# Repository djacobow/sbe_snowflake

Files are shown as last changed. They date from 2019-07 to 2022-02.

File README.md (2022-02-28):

# Electronic Snowflake

South Berkeley Electronics Snowflake

This is the public repo for the
[South Berkeley Electronics Snowflake](https://www.southberkeleyelectronics.com/home/snowflake).

SBE has chosen to discontinue this item and instead make the design
available publically for people who would like to build their
own.

The design is licensed under the
[Create Commons Attribution - ShareAlike 3.0 license](https://creativecommons.org/licenses/by-sa/3.0/), a copy of which is included in this repository.

## What you will find here

In this repo, you should find:

### Hardware

* DipTrace files for the design
* gerbers, exported from Diptrace, if you just went to send them to a PCB house
  for manufacture. The design uses a simple 2-layer board that can be manufactured
  with the basic offerings from PCBWay, JLCPCB and others.
* A complete BOM that you can use to order parts

I cannot provide detailed guidance on how to order and complete a PCB.
There is nothing particularly difficult about this design, but in order to
complete it you should be able to solder a QFP chips, as well as 0805 size
passives. Also, the WS2812C LEDs that the design is built around are quite
sensitive to heat, and not particularly easy to solder without damage.

### Software

* There are two versions of the firmware included. A basic one
  pretty much shows that you can control the LEDs, but does not
  use all the peripherals (the IR controller, light sensor, etc.

* The complete firmware that has *all* the light modes and features
  enabled.

Both should be easily built under recent version of the Arduino
platfor, targeting the "Pro Mini 8MHz". You may have to add this
to you board.config.

## Instructions for Arduino setup

Please find the Arduino setup instructions in
the User manual found on the resources page here:
https://www.southberkeleyelectronics.com/home/snowflake

The main bit of setup you need to do is:

* install a header on your board to receive the serial or ICSP connector,
  depending on which programming approach you intend to use.

* Add an entry to boards.text for a 8MHz pro mini (necessary snippet
  of `boards.txt` is included in this repo) The `boards.text` modification
  is only necessary if you use serial programming or if you intend to
  change fuse settings.

You can program from the Arduino environment, but I usually do "export
binary" to compiler an image, and then use a script called `flash.sh` to
program my devices using AVRdude and a USBtiny.

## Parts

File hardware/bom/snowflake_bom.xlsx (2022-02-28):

Item # | RefDes | Qty | Manufacturer | Manufacturer Part Number | Value | Description | Package / Pattern | Note | side | smd/th | Orientation | Preferred Source | Mouser | LCSC | 7/8/2019 LCSC | 7/8/2019 Mouser
1 | BT1, BT2, BTRST | 3 | Alps or asian equivalent | SKQGADE010 or other 4mmx4mm tactile switch |  | tactile switch | SKQGADE010 | subst OK same size, pressure, height | top | smd |  | lcsc | https://www.mouser.com/ProductDetail/ALPS/SKQGADE010 | https://lcsc.com/product-detail/Tactile-Switches_4-4-1-7-Plastic-head_C10852.html | x
2 | C1_1, C1_2, C1_3, C1_4, C1_5, C1_6, C2_1, C2_2, C2_3, C2_4, C2_5, C2_6, C3_1, C3_2, C3_3, C3_4, C3_5, C3_6, C4_1, C4_2, C4_3, C4_4, C4_5, C4_6, C5_1, C5_2, C5_3, C5_4, C5_5, C5_6, C30, C37, C70, C81,C301,C302,C305 | 37 | Yageo | CC0805KRX7R9BB104 | 100n | MLCC | CAP_0805 | subst OK same value, voltage, dialectric | top | smd |  | lcsc | https://www.mouser.com/ProductDetail/Yageo/CC0805KRX7R9BB104?qs=sGAEpiMZZMvsSlwiRhF8qgFnKIgZe697EuKjjg6fFBI%3D | https://lcsc.com/product-detail/Multilayer-Ceramic-Capacitors-MLCC-SMD-SMT_100nF-104-10-50V_C49678.html | x
3 | C31, C32, C34, C35, C36, C90, C92, C94 | 8 | Yageo | CC0805ZKY5V9BB105 | 1u | MLCC | CAP_0805 | subst OK same value, voltage, dialectric | top | smd |  | lcsc | https://www.mouser.com/ProductDetail/Yageo/CC0805ZKY5V9BB105 | https://lcsc.com/product-detail/Multilayer-Ceramic-Capacitors-MLCC-SMD-SMT_1uF-105-20-to-80-50V_C106838.html | x
4 | C91, C93, C95 | 3 | Murata | GRM32EC81C476ME15L or GRM32ER61C476KE15L | 47u | MLCC | CAP_1210 | subst OK same value, voltage, dialectric | top | smd |  | lcsc | https://www.mouser.com/ProductDetail/Murata-Electronics/GRM32EC81C476ME15L | https://lcsc.com/product-detail/Multilayer-Ceramic-Capacitors-MLCC-SMD-SMT_MuRata_GRM32ER61C476KE15L_47uF-476-10-16V_C77101.html | x
5 | D1 | 1 | Wurth | 150080RS75000 |  | chip LED (red) | LED_0805 |  | top | smd | silk line indicates cathode | mouser | https://www.mouser.com/ProductDetail/Wurth-Electronics/150080RS75000 |  | x
6 | D30, D31 | 2 | ON | RB751S40T1G |  | schottky diode | SOD-523 |  | top | smd | silk dot indicates cathode | lcsc | https://www.mouser.com/ProductDetail/863-RB751S40T1G | https://lcsc.com/product-detail/Schottky-Barrier-Diodes-SBD_ON-Semicon_RB751S40T1G_ON-Semicon-ON-RB751S40T1G_C232576.html | x
7 | D91 | 1 | Nexperia | PMEG2005EH,115 |  | schottky diode | SOD-123F |  | top | smd | silk dot indicates cathode | lcsc | https://www.mouser.com/ProductDetail/Nexperia/PMEG2005EH115?qs=sGAEpiMZZMvKM5ialpXrmlgHyKLJ2jqn | https://lcsc.com/product-detail/Schottky-Barrier-Diodes-SBD_Nexperia_PMEG2005EH-115_PMEG2005EH-115_C96233.html | x
8 | L301 | 1 | Taiyo Yuden | LBR2012T1R0M | 1u | 0805 inductor | IND_0805 | subst ok same value, >= 500mA max DC current | top | smd |  | lcsc | https://www.mouser.com/ProductDetail/Taiyo-Yuden/LBR2012T1R0M | https://lcsc.com/product-detail/New-Arrivals_Taiyo-Yuden-LBR2012T1R0M_C223265.html | x
9 | MIC30 | 1 | Knowles | SPW0442HR5H-1 |  | mems microphone | SPW0442HR5H |  | top | smd | opening to right, ground pins to left | mouser | https://www.mouser.com/ProductDetail/Knowles/SPW0442HR5H-1
10 | Q20 | 1 | Vishay | TEMT6000X01 |  | ambient light sensor | TEMT6000X01 |  | top | smd |  | lcsc | https://www.mouser.com/ProductDetail/Vishay-Semiconductors/TEMT6000X01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 | https://lcsc.com/product-detail/Ambient-Light-Sensors_VISHAY_TEMT6000X01_TEMT6000X01_C94098.html |  | x
11 | Q90, Q91 | 2 | Diodes Inc | DMP1045UQ-7 or DMP1045U-7 |  | P channel MOSFET | SOT-23 |  | top | smd |  | lcsc | https://www.mouser.com/ProductDetail/Diodes-Incorporated/DMP1045UQ-7 | https://lcsc.com/product-detail/MOSFET_Diodes-Incorporated_DMP1045U-7_Diodes-Incorporated-DMP1045U-7_C177033.html | x
12 | R2, R32, R93 | 3 | Vishay Dale | CRCW0805220RFKEAC | 220 | chip resistor 1% | RES_0805 | subst ok same value | top | smd |  | mouser | https://www.mouser.com/ProductDetail/Vishay-Dale/CRCW0805220RFKEAC |  | x
13 | R21, R30b | 2 | Bourns | CR0805-FX-5102ELF | 51k | chip resistor 1% | RES_0805 | subst ok same value | top | smd |  | mouser | https://www.mouser.com/ProductDetail/Bourns/CR0805-FX-5102ELF |  | x
14 | R31, R38, R39, R94 | 4 | Vishay Dale | CRCW080510K0FKEAC | 10k | chip resistor 1% | RES_0805 | subst ok same value | top | smd |  | mouser | https://www.mouser.com/ProductDetail/Vishay-Dale/CRCW080510K0FKEAC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 |  | x
15 | R33, R34, R90 | 3 | Bourns | CR0805-FX-1004ELF | 1M | chip resistor 1% | RES_0805 | subst ok same value | top | smd |  | lcsc | https://www.mouser.com/ProductDetail/Bourns/CR0805-FX-1004ELF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 | https://lcsc.com/product-detail/Chip-Resistor-Surface-Mount_BOURNS-CR0805-FX-1004ELF_C204141.html | x
16 | R1, R35, R40 | 3 | Yageo | RC0805FR-072K2L | 2k2 | chip resistor 1% | RES_0805 | subst ok same value | top | smd |  | lcsc | https://www.mouser.com/ProductDetail/Yageo/RC0805FR-072K2L?qs=sGAEpiMZZMtlubZbdhIBILn9RB3fCJQ4asklwXRJaEE%3D | https://lcsc.com/product-detail/Chip-Resistor-Surface-Mount_2-2KR-2201-1_C114561.html | x
17 | R36, R301 | 2 | VishayDale | CRCW0805100KFKEAC | 100k | chip resistor 1% | RES_0805 | subst ok same value | top | smd |  | mouser | https://www.mouser.com/ProductDetail/Vishay-Dale/CRCW0805100KFKEAC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 |  | x
18 | R37, R92 | 2 | Vishay Dale | CRCW08054K70FKEAC | 4k7 | chip resistor 1% | RES_0805 | subst ok same value | top | smd |  | mouser | https://www.mouser.com/ProductDetail/Vishay-Dale/CRCW08054K70FKEAC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 |  | x
19 | U31 | 1 | ST Micro or TI | LM358D |  | dual opamp | SOIC-8 |  | top | smd |  | lcsc | https://www.mouser.com/ProductDetail/Texas-Instruments/LM358D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 | https://lcsc.com/product-detail/General-Purpose-Amplifiers_STMicroelectronics_LM358DT_LM358DT_C9418.html | x
20 | U70 | 1 | Vishay | TSOP77238TR |  | 38kHz IR receiver | TSOP77X |  | top | smd | mount with lens up | mouser | https://www.mouser.com/ProductDetail/78-TSOP77238TR |  | x
21 | U301 | 1 | Atmel | ATMEGA328P-AU |  | microcontroller | TQFP-32 |  | top | smd | silk dot corresponds with chip dot | mouser | https://www.mouser.com/ProductDetail/Microchip-Technology-Atmel/ATMEGA328P-AU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 |  |  | x
22 | WS1_1, WS1_2, WS1_3, WS1_4, WS1_5, WS1_6, WS2_1, WS2_2, WS2_3, WS2_4, WS2_5, WS2_6, WS3_1, WS3_2, WS3_3, WS3_4, WS3_5, WS3_6, WS4_1, WS4_2, WS4_3, WS4_4, WS4_5, WS4_6, WS5_1, WS5_2, WS5_3, WS5_4, WS5_5, WS5_6 | 30 | World Semi | WS2812C |  | addressable RGB LED | WS2812B | I can only get these from LCSC or AliExpress. If you have alternate suppliers in China, please let me know. Note that I want the WS2812C not the WS2812B | top | smd | silk triangle corresponds with triangle on part | lcsc |  | https://lcsc.com/product-detail/Light-Emitting-Diodes-LED_5050-RGBIntegrated-Light-4Pin_C114587.html | x
23 | BAT90 | 1 | Keystone or MPD | 2479 (Keystone) or BC3AAAPC (MPD) |  | 2xAAA TH battery holder | Keystone_2479_nohole |  | bottom | th |  | mouser | https://www.mouser.com/ProductDetail/Keystone-Electronics/2479
24 | J90 | 1 | Wurth or Korean HRO Parts | 614105150721 (Wurth) OR U-D-M5DD-W-1 (Korean HRO) |  | Vertical TH micro-USB type B |  | subst ok same footprint and still micro-usb-b | bottom | th |  | lcsc | https://www.mouser.com/ProductDetail/Wurth-Electronics/614105150721 | https://lcsc.com/product-detail/Micro-USB-Connectors_Korean-Hroparts-Elec-U-D-M5DD-W-1_C145795.html
 |  | total parts |  | unqiue parts
 |  | 114 |  | 24
Do not Fit
Item # | RefDes | Qty |  | Manufacturer Part Number | Value | Type | Pattern | Note | side | smt/th | orientation |  | Mouser
25 | C80 | 1 |  |  | 100p | MLCC | CAP_0805 |  | top | smd
26 | D80 | 1 |  | BAT15-04W |  | schottky microwave diode | SOT-323-3 |  | top | smd |  |  | https://www.mouser.com/ProductDetail/Infineon-Technologies/BAT-15-04W-H6327
27 | L80 | 1 |  | CE201210-22NJ | 22n | SMD inductor | IND_0805 |  | top | smd |  |  | https://www.mouser.com/ProductDetail/652-CE201210-22NJ
28 | J80 | 1 |  | Hirose U.FL-R-SMT-1(10) |  | u.fl antenna connector | U.FL-R-SMT-1 |  | top | smd |  |  | https://www.mouser.com/ProductDetail/Hirose-Connector/UFL-R-SMT-110
29 | R80 | 1 |  | CR0805-FX-1004ELF | 1M | chip resistor | RES_0805 |  | top | smd |  |  | https://www.mouser.com/ProductDetail/Bourns/CR0805-FX-1004ELF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
30
Optional
31 | C303, C304 | 2 |  |  | 22p | MLCC | CAP_0805 |  | top | smd
32 | JPGM | 1 |  | generic 2x3 0.1" header |  | 0.1" header | avricsp |  | top | th
33 | JPWR | 1 |  | generic 3x1 0.1" header |  | 0.1" header | hdr2x2 |  | top | th
34 | JSRL, JX1, JX2 | 3 |  | generic 1x6 0.1" header |  | 0.1" header | hdr6 |  | top | th
35 | Y301 | 1 |  | TSX-3225 16.0000MF09Z-AC3 | 16MHz | crystal | TSX-3225 |  | top | smd |  |  | https://www.mouser.com/ProductDetail/Epson-Timing/TSX-3225-160000MF09Z-AC3
36 | D90 | 1 |  |  |  | chip LED (white) | LED_0805 |  | top | smt
37 | R91 | 1 |  |  | 3k9 | chip resistor | RES_0805 |  | top | smt
38 | D92 | 1 |  | S1D or (MDD) Jiangsu Yutai Elec ES1D |  | silicon rectifier diode | DO-214AC |  | top | smt |  |  | https://www.mouser.com/ProductDetail/ON-Semiconductor-Fairchild/S1D?qs=sGAEpiMZZMuQUXCJI7Y4lndcBDLwb6fD | https://lcsc.com/product-detail/Diodes-Rectifiers-Hyperfast_Jiangsu-Yutai-Elec-ES1D_C13829.html
39 | R30a | 1 |  | RC0805FR-0747KL | 47k | chip resistor | RES_0805 |  | top | smd |  |  | https://www.mouser.com/ProductDetail/Yageo/RC0805FR-0747KL?qs=sGAEpiMZZMtlubZbdhIBIMN3bZRLqVxtnCzLsA88C9Q%3D

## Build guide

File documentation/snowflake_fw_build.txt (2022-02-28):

Building the Snowflake Firmware and Burning it onto Snowflake Board

1. Warranty

THE SOFTWARE ENCLODED IS PROVIDED "AS-IS", WITHOUT WARRANTY OF ANY KIND
(EITHER EXPRESS OR IMPLIED), INCLUDING BUT NOT LIMITED TO ANY IMPLIED
WARRANTIES OF MERCHANTABILITY OF FITNESS FOR A SPECIFIC OR GENERAL
PURPOSE.

2. Arduino Installation

This software can be compiled inside the standard Arduino
environment. It has been successfully tested with Arduino 1.8.9 and 1.8.8,
both on Linux.  Arduino version 1.8.10 does *NOT* work, and is not
recommended.

Install the Arduino Software as you normally would for your platform.

3. Modifying boards.txt

The Atmega on the snowflake operates at 8 MHz and without the use
of external clock crystals. There are no standard Arduino boards 
in the standard boards.txt that describe such a board, so you need to
add it.

The following lines, added to boards.txt, will suffice:

---- CUT HERE ----
## RAW 328p internal clock 
## ---------------------------------------------------
pro.menu.cpu.8MHzatmega328int =ATmega328P 3.3V 8 MHz INTERNAL OSC
pro.menu.cpu.8MHzatmega328int.upload.maximum_size=30720
pro.menu.cpu.8MHzatmega328int.upload.maximum_data_size=2048
pro.menu.cpu.8MHzatmega328int.upload.speed=57600
pro.menu.cpu.8MHzatmega328int.bootloader.low_fuses=0xE2
pro.menu.cpu.8MHzatmega328int.bootloader.high_fuses=0xD8
pro.menu.cpu.8MHzatmega328int.bootloader.extended_fuses=0xFF
pro.menu.cpu.8MHzatmega328int.bootloader.file=atmega/ATmegaBOOT_168_atmega328_pro_8MHz.hex
pro.menu.cpu.8MHzatmega328int.build.mcu=atmega328p
pro.menu.cpu.8MHzatmega328int.build.f_cpu=8000000L
---- CUT HERE ----

These lines should be added to:

<install_location>/arduino/avr/boards.txt

or, if you have updated your boards package in the IDE, the right
file might be in:

<home_directory>/.arduino15/packages/arduino/hardware/avr/<version>/boards.txt

After you have made the changes, save the file and restart the Arduino
IDE

4. Installing IRLib2 Library

This code makes use of the IRLib2 library, found here: 

https://github.com/cyborg5/IRLib2

You can download the entire library and put it into your
sketchbook/libraries folder. Be sure to follow the advice in their
instructions that each sublibrary be installed at the top level of your
libraries folder.

5. Installing the sketch

The sketch is provided in a zipfile enclosed. Unzip it into your
sketchbook folder. You then should be able to open it directly in the
Arduino IDE

6. Choosing the Board

Within the Arduino IDE, choose Tools => Board, and choose "Arduino Pro
or Pro Mini".

Then, choose Tools => Processor and choose "3.3V 8MHz INTERNAL CLOCK".

If the "INTERNAL CLOCK" option is not there, you did not edit your
boards.txt, or you edited the wrong one. Find the right file, make the
changes and restart the Arduino IDE

7. Compilation

At this point clicking the "check mark" should allow the sketch to
compile without errors.

8. Burning Bootloader

To get the correct fuse values for the Atmega to run without a crystal,
you should burn the bootloader.

You will have to do this using an ICSP device programmer.  Each programmer
has slightly different instructions. I can't explain them all, but
basically, you select you programmer and then choose "Tools => Burn
Bootloader".

8. Upload

If you successfully burned the bootloader, you can upload the sketch
in the normal manner using a serial cable attached to JSRL.  However,
since you have the ICSP programmer out and in use, it's just as easy to
choose "Sketch => Upload Using Programmer" to upload the sketch.

9. Burning many boards

If you have to program many boards, you may find it more convenient to
use a simple script to do so. I have provided such a script for linuex
(flash.sh). First, use the IDE and choose "Sketch => Export Compiled
Binary". This will create two .hex files in the sketch folder. Then run
flash.sh to write those files to your boards. The script also sets the
appropriate fuses for internal oscillator at 8MHz. The script works with
the USBtiny programmer, but you can adapt it for other programmers.

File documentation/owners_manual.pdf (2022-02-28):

## South Berkeley Electronics Electronic Snowflake Model I

Manual Rev 0.090 November, 2020

What is it?

Precautions

Basic Operation
“On” button
“Pattern” Button
“Mode” Button

What all the modes and settings do Patterns
“Settings” Pattern
Variations
Speed
Mode
Brightness
Duration

Remote Control Operation

Power
Low Batteries
Turning “Off”

Storage & Battery Life

Technical Stuff for Haxx0rs Arduino Setup
Step 0:
Step 1:
Example Sketch and Schematics Headers and connections
Clock
Reserved IO Pins

How does this work? / Theory of Operation The LEDs
The Sound
The Remote
Power

Warranty
Congratulations on your purchase of the South Berkeley Electronics Snowflake! We hope that you enjoy your new toy and that it will provide you years of nerdy entertainment.

## What is it?

The electronic snowflake was conceived as a Christmas tree ornament for people with electronics enthusiasts in their family. We thought it would be fun to make a circuit board in the shape of a snowflake with colored lights.

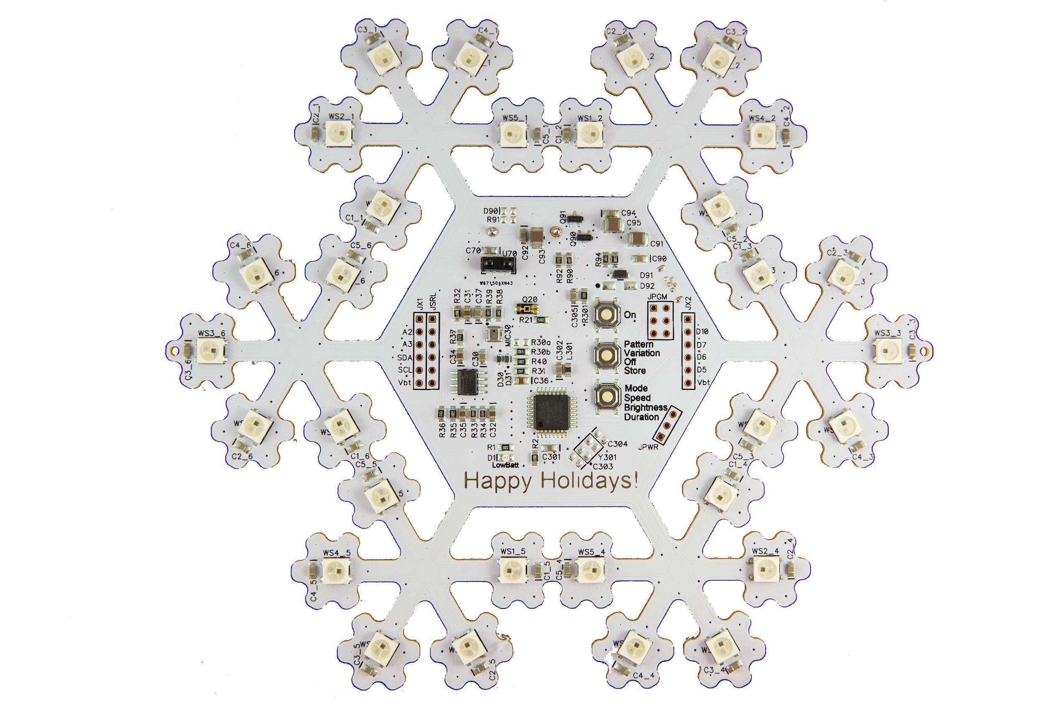
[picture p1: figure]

However, we might have gotten a little carried away. After all:

- shouldn’t a light-up snowflake automatically adjust to ambient lighting?
- and wouldn’t it be cool if it responded to sound?
- and if you put it high in a tree, wouldn’t it be nice to be able to control it remotely?
- and finally, since it is based on the same technology as the popular Arduino, shouldn’t it be easy to reprogram?

The answer was YES, of course it should do those things!

## Precautions

The snowflake consists of electronic components soldered onto a bare circuit board. We think this looks pretty cool. The board and components are lead-free, but the snowflake should not be used where small children might put it in his or her mouth. Furthermore, the item is somewhat delicate, particularly the USB power connector on the reverse side, so please be gentle when handling.

## Basic Operation

Operation of the snowflake is simple, if a bit quirky. There are three buttons that control several functions. Because of all the functions possible, the buttons each can do more than one thing. The time you hold down the button determines what command you issue.

“On” button

Okay, we lied a bit. This one is simple.

function | duration | Meaning
Turn on | Any duration | This just turns the unit on if it is not already and resets it.

“Pattern” Button

function | duration | Meaning
pattern | Quick press | Advances the unit through the next light pattern.
variation | 1-2 seconds | Advances to the next variation of the current light pattern. Some light patterns respond to variation changes, some do not, so this command doesn’t always do something.
off | 5-6 seconds | Turns the snowflake off. (Note: on battery power, off is really off. On USB power, the unit is in a low-power state so that the remote control can still wake it.
store | > 10 seconds | Stores all the current settings to non-volatile memory as your “favorite” (preferred default). When you reset or next use the “on” button,the snowflake will start in

the same configuration it was in when you issued the store.

“Mode” Button

function | duration | Meaning
mode | Quick press | Switch the sound mode. There are three sound modes: - No sound response (sound mode off) - “VU” meter mode - Flash to rhythm mode
speed | 1-2 seconds | Adjusts the update speed of the light pattern. The pattern update speeds can be adjusted from very fast to very slow in 9 steps. The default is a moderate speed.
brightness | 5-6 seconds | Adjusts the overall brightness of the LEDs. Note that the LEDs will always respond to ambient lighting conditions. This setting essentially adjusts the “top” of the output brightness range.
duration | > 10 seconds | Adjust the amount of time the unit stays on. The default is 30 minutes.

## What all the modes and settings do

Patterns

The most basic setting of the snowflake is the “pattern”. This is the effect or animation that is currently being displayed. Patterns vary from spinning colors to cylon sweeps, and all manner of random flashing in between.

As of the writing of this manual, there are thirteen patterns, plus a special “settings” pattern, which I will describe below.

Pattern Names

Chaser | sparkle | rainbow | sparse | snake | leaves | flash | cylon | solid | minicircle | inching | pulse | fade | lines

“Settings” Pattern

One of the patterns available on the snowflake is not much fun, but it is helpful. I call it the “settings” pattern. In this pattern you can see the current setting of the speed, turn-off delay, and maximum brightness. Three LEDs will be lit continuously. The blue one tells the speed setting. It rotates around the LEDs on one “arm” of the snowflake as you advance the setting. The magenta one does the same for the turn-off delay, and the teal one does the same for the brightness setting.

If, in this mode, you make very long press on the second button to “store” your settings, they will all be stored, including the current pattern. That will be a bit boring, as the settings pattern itself will become the default, which you probably do not want. However, if you want to store the speed, shutdown delay, etc, you can certainly just do that in this pattern, then switch to another pattern and issue the “store” again, and that pattern will be stored without overwriting the other setting.

Variations

Some patterns also have variations. These are slight variation on the pattern, using the same overall code. For example, what colors to use in a “rainbow” pattern, which way to spin, and how many lights to twinkle.

The variations do not have names. You’ll just have to play around a bit to see what they do.

Speed

This determines how fast the animation runs. There are nine speed settings. Each step goes slower, until it wraps around and goes fast. The default speed is a middle value.

Update periods

70 ms*
(default)
100 ms | 200 ms | 500 ms | 1 s | 5 s | 5 ms | 20 ms | 40 ms

Mode

This determines if the snowflake will respond to sound. There are three sound modes. The first is off --no sound response. The second mode causes the snowflake to act like a sort of “VU Meter”, lighting more LEDs the louder the sound. The third mode is a mode where it will enable all the LEDs together, according to the general sound level.

One thing to understand about the sound modes is that they work independently of the pattern. Think of the sound mode as acting like a mask overlaid on the pattern that would otherwise be lit. If the pattern has few LEDs lit to begin with, it might be hard to tell that the sound mode is working at all. Therefore, sound mode is the most fun with patterns that would have had most of the LEDs lit without sound mode enabled.

Sound Modes

Normal, not sound sensitive (default)

Sound sensitive “VU meter” Sound sensitive “beat flash”

Brightness

The snowflake is equipped with an ambient light sensor. This is nice, as the snowflake will auto-dim in a dark room. When you use the brightness adjustment you are actually adjusting the maximum brightest that a pattern can use. Patterns that vary LED brightness still do so, but in a range determined by this setting.

Brightnesses

Medium
(default)
medium-bright | bright | brightest | dim

Duration

The snowflake turns itself off after a preset period, which you can control. The settings are as below:

On Times

30 min
(default)
1 hr | 2 hr | 3 hr | 6 hr | 12 hr | 21 hr | 5 min | 15 min

## Remote Control Operation

The snowflake can be operated by the infra-red remote control provided just as easily as from the front panel buttons. The same functions are available, but they are mapped to buttons as follows:

Button | Meaning
1, ▶ | Go to next pattern
◀ | Go to previous speed
2 | Go to next variation
3 | Save the current state as the power-on default
4 | Increment the mode
5,▼ | Go to next speed
▲ | Go to previous speed
6 | Increment the brightness
7, ✱ | Turn off, or if it’s already off, back on †
9, # | Increment turn-off delay
0 | Increment “automatic mode” (changes patterns on it own)

†Hitting “7” or “✱” to turn off the snowflake will have different behavior depending on whether the snowflake is running on batteries of USB power. If on batteries, it will turn off and you will not be able to turn it back on again via the remote. This is a feature designed to keep from running the batteries completely down. When “off”, but powered via USB, the unit keeps the IR receiver powered so that it can work. On batteries, the IR receiver is also powered down, so it cannot be used to wake the unit!

Note: Depending on how you ordered the snowflake, the remote may not have come with a battery. This is because of complexities in shipping regulations for lithium batteries. If you did not get a battery, contact dave@southberkeleyelectronics, and we’ll send you one!

## Power

The snowflake can be powered either of two ways:

- by three AAA batteries
- by a USB power supply with a micro-USB connector

To use battery power, simply insert fresh batteries into the rear holder, observing the polarity marked. You can also power the snowflake from just about any USB charger with a micro-USB connector. Just plug it into the plug on the back. This can be nice if you want to hang the snowflake in a tree and you already have an AC cord in there. The device will use the USB power if is available, otherwise it will revert to the batteries. There is no need to remove the batteries while plugged into USB.

Note: The micro-USB connector is more delicate than we’d like. Use care when removing a power supply from the connector.

Low Batteries

If the batteries are getting low, the unit might malfunction and do strange things. To avoid this, the voltage is monitored. If it gets too low, the unit will turn off the main LEDs and flash a small, red LED marked “LowBatt” for about 20 sceonds, then turn off.

Note: “sound mode” (described further below) really likes fresh batteries. Partly depleted batteries that do not trigger the low battery warning may still cause the sound sensitive mode not to work. The solution is USB power or a fresh set of batteries.

Turning “Off”

Turn-odd behavior is slightly different depending on whether the snowflake is running on batteries or USB:
- When running on batteries and it turns off (either because you turned it off, or it turned itself off after the pre-set time), it will turn completely off in order to minimize battery drain. It cannot be turned back on via the remote control.

- When has been running from USB power, turning the snowflake off will put the unit into a low-power state that keeps the infrared receiver powered up. This uses just a tiny bit of power, but allows the remote control to turn the unit back on.

## Storage & Battery Life

When the device is in the “off” state, battery draw will be quite low, but it is not zero. (For those playing at home: it’s about 85 µA, mostly through D91/2, R93, R94, I think.) For the period a Christmas tree is up, this should not drain your batteries very much, but over a year in storage, it surely will. Nobody likes leaky and dead batteries, so I strongly recommend that you remove the batteries between holidays, in order to avoid leaky ickiness and potential damage to the battery holder.

## Technical Stuff for Haxx0rs

This board comes ready to use as a fun Christmas ornament or toy, and you can enjoy it just like that. But if you want to write code to make a new cool pattern or just want to hack on it a bit, you can do that, too!

The board comes configured with the Arduino Bootloader already installed, and has an FTDI-style serial port. (You’ll need to install a header.) So you can just hook up a serial cable and the Arduino IDE and reprogram to your heart’s content.

Note: The USB port does not support serial programming. You need to use the FTDI serial header.

We don’t have the resources to provide a complete Arduino tutorial here, but if you are already familiar with the Arduino ecosystem, the technical details you’ll need to know are below. These should be sufficient if you are already familiar with the Arduino family and just need to know what is “special” about this board.

### Arduino Setup

We did all the development for this project using the Arduino 1.8.9 environment under Linux. We suspect, but cannot guarantee that any 1.8.x+ version should work on any platform that runs Arduino.

In order to program this board you will need to take a few additional setup steps.

Step 0:

If you intend to use a hardware programmer (ICSP) with this board and the Arduino IDE. You’ll want to first solder in the 2x3 ICSP header and then create an entry in boards.txt that matches this device.This file is usually found in:

<install>/arduino-1.8.9/hardware/arduino/avr/boards.txt

This is so that the IDE understands it is dealing with an 8 MHz board using the internal oscillator.

If you are going to do only serial uploads using the bootloader, you can skip this. But if you plan to use the ICSP programmer and/or need to burn the bootloader again, this is important.

I simply took the entry for an 8 MHz Arduino Pro Mini and made the fuse changes to use the internal oscillator:

The additional lines are as below:

## RAW 328p internal clock

## ---------------------------------------------------pro.menu.cpu.8MHzatmega328int =ATmega328P 3.3V 8 MHz INTERNAL OSC

pro.menu.cpu.8MHzatmega328int.upload.maximum_size=30720 pro.menu.cpu.8MHzatmega328int.upload.maximum_data_size=2048 pro.menu.cpu.8MHzatmega328int.upload.speed=57600 pro.menu.cpu.8MHzatmega328int.bootloader.low_fuses=0xE2 pro.menu.cpu.8MHzatmega328int.bootloader.high_fuses=0xD8 pro.menu.cpu.8MHzatmega328int.bootloader.extended_fuses=0xFF pro.menu.cpu.8MHzatmega328int.bootloader.file=atmega/ATmegaBOOT_168_atmega328_pro_8M Hz.hex
pro.menu.cpu.8MHzatmega328int.build.mcu=atmega328p pro.menu.cpu.8MHzatmega328int.build.f_cpu=8000000L

After making this change, restart the Arduino IDE and choose “ATmega328P 3.3V 8 MHz INTERNAL OSC” from the board menu:

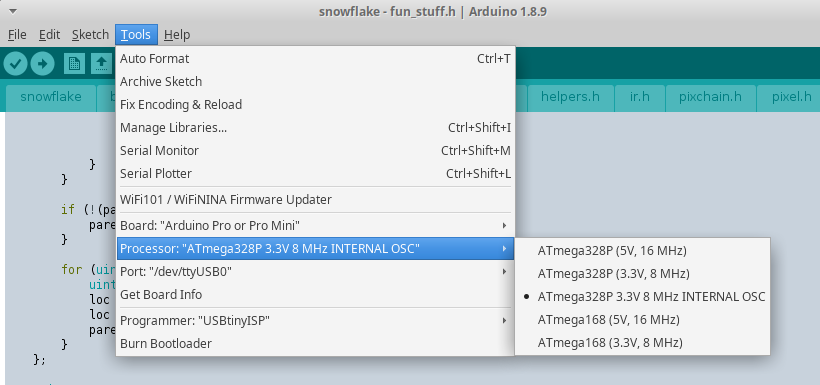
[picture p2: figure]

Alternatively, if you only plan on using the normal Arduino upload over a serial cable, then you will want to solder in a 6x1 header for JSRL, and you can skip editing boards.txt and just choose Atmega328P (3.3V 8 MHz), which is already in the default boards.txt.

Step 1:

If you want to use the IR receiver, you will need an IR library. I’ve been using IRLib2. Follow the instructions on their site: https://github.com/cyborg5/IRLib2. Other similar libraries will also probably work. Use what you like.

### Example Sketch and Schematics

A full schematic, some additional documentation, and a sample firmware are all available at https://github.com/djacobow/snowflake.

PCB layout / gerbers and the complete sketch are not available.We want to make this project as open as possible, but it is not an open-source product. The shape is our own intellectual property and we want to have some minimal protection against commercial copying. If you would like to make this board yourself, or need to reprogram that original sketch after overwriting it, we will send you the necessary files on an individual basis and the condition that you do not share them with others. Simply contact dave@southberkeleyelectronics.com.

### Headers and connections

The board has several headers to enable you to use it in your own projects. Several, but not all Arduino pins are brought out to headers. This makes it more limited than a real Arduino but infinitely more flexible than your average holiday decoration.

You will notice that the headers are not populated with pins or sockets. For most people who will not hack their board, this makes the board more comfortable in the hand. Any ordinary 0.1” pins/sockets can be used. If you order directly from me on Tindie, I will include these by request, but you’ll have to solder them yourself.

### Headers provided for hacking use

The following header locations make it easy to use some of the Atmega328p pins for your own projects/purposes. Note that some of these pins are also shared with peripherals on the board.

Header Connection | Purpose / Description
JPGM | A standard Atmel 6-pin ICSP connector. If you have a hardware programmer such as an AVRISP, you can program the Atmega328p directly with this header.

| This connector does not come with a pin header installed; you will have to solder one in. You can use this for programming, but of course, you can use it to access the SPI signals, too. D10, traditionally used as an SPI “SS” pin is also available on JX2.
JX1 | This header provides access to four signals, plus power and ground. The top pin is ground, followed by “A2”, “A3”, “SDA”, and “SCL”. The bottom pin is power. This will be about 4-4.5 V if running off batteries, or 5V if running from USB power. Note: that A2 and A3 are shared with the snowfake’s power controls (see reserved pin table below). You can use these to sense whether the snowflake is on or not. You probably do not want to use these for general purpose IO.)
| “original” FTDI cables. You can plug such a cable in directly and access the serials lines for debug or programming. The pin order matches a real FTDI cable. (https://www.sparkfun.com/products/9717) Black is the square pin at the top near the header marking, green at the bottom.
Cable | Header | Color
ground | ground | black
cts/ | No connection | brown
Vcc | No connection | red
Tx from cable | Rx to board | orange
Rx to cable | Tx from board | yellow
dtr/ | dtr/ (reset) | green
JSRL | This is the “standard” 6 pin serial connection as featured in the

Notes:

CTS/ is not connected, which is just like any other Arduino board. Vcc is also not connected. This was an intentional choice to avoid having the serial cable try to power the board. Instead, power the board through batteries the USB connector at the back, or JPWR.

Cheap CH340 adapters (https://www.sparkfun.com/products/14050) work as well as a real FTDI connector.

Because the internal oscillator of an Atmega is not particularly precise and these boards have no crystal, you may have trouble using the serial port at very high speeds. If you get garbage from your serial port, consider lowering the speed to 38400 or even 19200. I have not seen any boards that do not work at 19200.

Note that the arduino bootloader is installed but if you program with an ICSP programmer on JPGM, the bootloader will be overwritten, so serial programming will not work again until you re-burn the bootloader. It is this step that really requires that modified boards.txt as described above.

JX2 | Provides ground at the top, and Vcc at the bottom, and access to pins D10, D7, D6, and D5.
JUSB | This connector is only for 5V power over USB.
JPWR | A 3 pin header with access to always on power, switched power, and ground

### Clock

The snowflake is configured to use the internal 8 MHz of the Atmeg328p, and the clock divider is set to divide by 1, so the Atmega runs at 8 MHz. This is adequate for most purposes, but if you want to run at 16 or 20 MHz, or if you want a more accurate clock, pads for Y301, C303, and C304 are available to use an external crystal and its associated capacitors. You will also obviously have to set the appropriate fuse bits on the Atmega to enable this. We have tested this functionality and it works.

Be forewarned: if you set the fuse to use an external crystal and such a crystal is not present or damaged, you will have a difficult time coaxing the Atmega to respond at all!

### Reserved IO Pins

### Reserved Pins and Their Use

The following pins of the Atmega328p are connected to hardware on the board, so you generally cannot use them for any purpose other than what it says they do here. This table will help you program the board.

Pin | header | Use
A3 | JX1 | This pin controls power to the IR receiver. It is connected directly to the VCC pin of the IR module. To turn the IR module on, I suggest: pinMode(A2,OUTPUT); digitalWrite(A2,HIGH); To turn it off, I suggest: digitalWrite(A2,LOW); pinMode(A2,INPUT); For reference, the IR receiver is a TSOP77238 or TSOP77438. https://www.vishay.com/docs/82471/tsop772.pdf
A2 | JX1 | This pin controls power to most of the circuit: LEDs, microphone, opamp, associated resistors. These all would draw quiescent power if they could not be turned off. The use of this pin is inverted. Driving it LOW turns the power on. Driving it HIGH or turning the pin to an input turns the power off.
A1 | n/a | The ambient light sensor is connected to this pin. Brighter light causes this pin to be pulled higher. You can read it directly with analogRead(). Do not set this pin for use as an output; you may damage the phototransistor. The light sensor is a TEMT6000X01 pulled up through a 51k resistor. http://www.vishay.com/docs/81579/temt6000.pdf
A0 | n/a | The sound detection circuit is connected to this pin. The sound detection circuit uses an operational amplifier configured as a precision rectifier followed by a low-pass filter to convert sound into a loudness envelope. You can read this pin with analogRead(A0) to get an overall loudness sense.
| | Because of limited gain in the analog stuff, you will generally not get full scale readings.
| | The microphone is from Knowles: https://www.mouser.com/datasheet/2/218/knowles_03312017_SPW 0442HR5H-1%20Datasheet%20Rev%20E-1173676.pdf. (https://www.mouser.com/datasheet/2/218/knowles_03312017_SPW0442HR5H-1%20Datasheet%20Rev%20E-1173676.pdf) The opamp is a generic LM358 equivalent.
D2 | n/a | This is the input from the TSSOP77x38 (https://www.vishay.com/docs/82471/tsop772.pdf) IR receiver module.
| | The IR transmitter included with the kit uses 32-bit NEC codes. However, I have tried this detector with various 38 kHz remotes, and they all seemed to work. However, the included sketch only

| | understands NEC and Sony numeric codes.
D3 | n/a | This pin is connected to the LowBatt LED. Driving it high turns the LED on. You could also use this as a general-purpose debug LED.
D4 | n/a | This pin drives the data-input of the LED chain. The LEDs are like the Adafruit NeoPixels. (https://learn.adafruit.com/adafruit-neopixel-uberguide/the-magic-of-neopixels) They are World Semi WS2812C’s: http://www.world-semi.com/Certifications/details-116-4.html. You can use the NeoPixel Library (https://github.com/adafruit/Adafruit_NeoPixel) to drive these pixels. In my sketch I do not use the Adafruit code directly. Instead, I cribbed what I needed from their library into my own simpler code.
D8 | n/a | This is connected to the mode button. This button is wired to pull the pin down, and there is no external pullup resistor. For it to work, you need to configure the pin as INPUT_PULLUP.
D9 | n/a | This is the pattern button. This button is wired to pull the pin down, and there is no external pullup resistor. For it to work, you must configure the pin as INPUT_PULLUP.

## How does this work? / Theory of Operation

The snowflake is actually a very simple device in principle, but it uses some sophisticated components.

The LEDs

Probably the most interesting are the color LEDs themselves. They are WS2812C LEDs from a Chinese company called World Semiconductor.

What’s interesting about these parts is that they contain, in one small package, not only separate red, green, and blue emitters, but also a controller chip that is capable of driving those three colors to any of 256 different brightness levels each. The only pins on these LED chips are power, ground, data-in, and data-out. The way you communicate with those chips is by “shifting in” 24 bits (8 bits for each color) one at a time. Once you pause, the LED chips use that data to drive the LEDs at a certain brightness, until you shift in something else. The LED pins also have an output pin, whereby everything you shift in is shifted out, but 24 bits later. This lets you chain a bunch of WS2812Cs up, so that you can still control them with a single pin. In the snowflake, we have 30 such LEDs arranged in a chain, connected to a single pin of the microcontroller chip.

The software running on the microcontroller chip, then, simply needs to determine what colors it wants in all the LEDs, and then shift out 3*8*30 (720) bits of information, every time it wants to redraw the pattern. Simple! Well, a complicating factor is that there is no “clock” reference to help with synchronizing this serial data, so the timing of the data pulses themselves is critical.

A lot of folks who play with LEDs may recognize the more common WS2812B rather than the WS212C used here. The difference is that the “C” are less bright and consume less current. They’re better for a battery-powered device like this.

The Sound

Of course, the snowflake has some other tricks up its sleeve. It can respond to sound. This is accomplished by way of a very small micromachine (MEMS) microphone (labeled MIC30) on the board. This is similar to the microphones found in phones. It generates a very small signal in response to sound. A dual op-amp chip (U30) amplifies and rectifies this signal in two steps. The rectified (positive-going only) output is then filtered so that the sound is converted into a sort of “loudness” waveform, and that is sent to one of the microcontroller’s input pins where an analog-to-digital converter (ADC) converts it into data which the program can use. A similar process occurs for the light sensor, except no op-amp is required.

The Remote

The unit can respond to infra-red signals from a remote control. For this, an infra-red diode attached to some conditioning electronics (U70) receives IR signals and decodes them into a simple bit stream, which goes to a microprocessor pin for decoding. A single IR frame takes some time to transmit, and that can be longer than the idle time between LED updates. To avoid lost key-presses, LED updates are skipped while an IR code reception is in progress.

Power

The microcontroller on the snowflake is capable of going into a very deep sleep mode where it draws only a few 10’s of nano-amps. Compared to the self-discharge rate of batteries, this is basically nothing. However, other parts on the board are a bit more power hungry. The LEDs draw a few 10’s if micro-amps of current, even when they are not outputting light. Multiplied by 30, this is enough to drain batteries over a few weeks. Also, the opamp in the sound circuit and the infrared remote detector all draw power.

To deal with this, the snowflake has a power transistor that the microcontroller can turn on and off to power up the other devices on the board. The LEDs, opamp, microphone, and a few other sundries are on this controllable power rail. The IR receiver for the remote is powered separately, directly through an output pin of the microcontroller. This lets the snowflake enter a semi-low power mode, where the LEDs are powered down, but the snowflake will still respond to remote IR codes.

One last complexity in managing power is making sure that USB power does not try to “back charge” any batteries. At best, it harms most batteries to try to charge them, and at worse, it could be dangerous (they could leak or get hot). So, there is a circuit on the snowflake that essentially disconnects the batteries from the rest of the snowflake when USB power is present.

## Warranty

This snowflake comes with a limited warranty from South Berkeley Electronics. It covers any defects in material or workmanship under normal use for one full year from the date of purchase. During the one-year warranty period, South Berkeley Electronics will repair or replace the snowflake at no charge. Contact us directly for warranty issues.

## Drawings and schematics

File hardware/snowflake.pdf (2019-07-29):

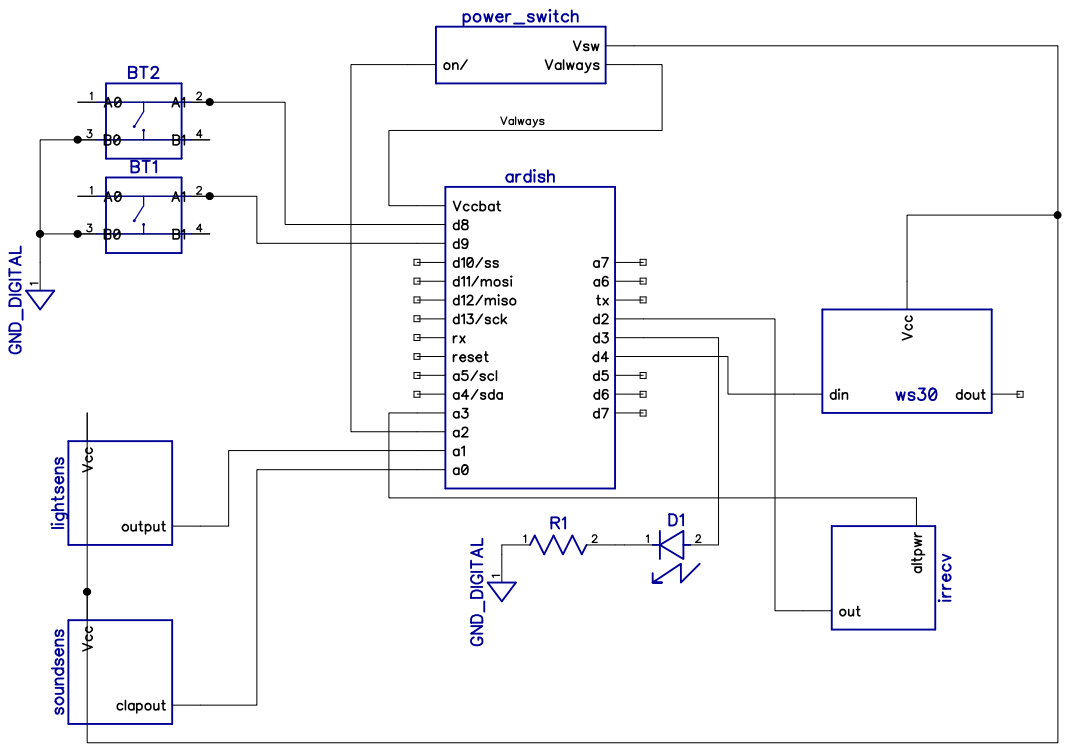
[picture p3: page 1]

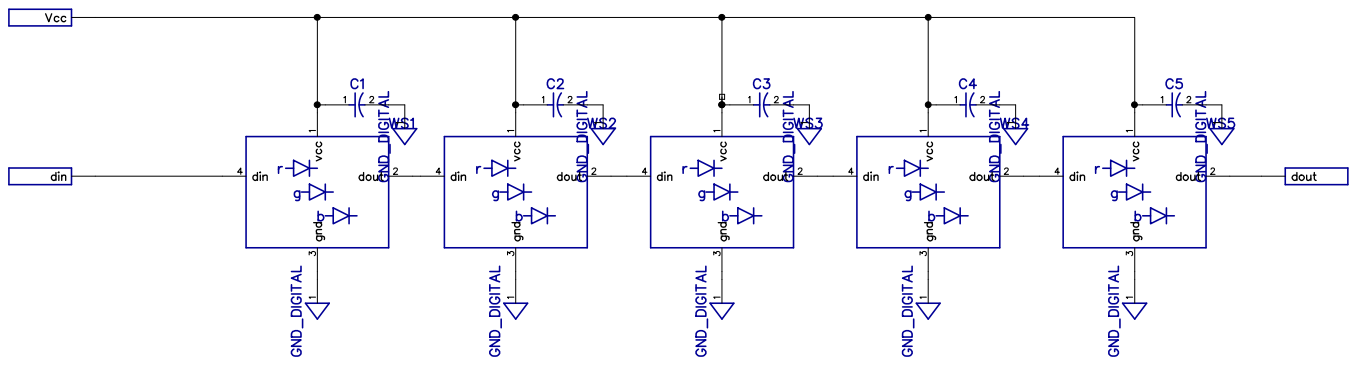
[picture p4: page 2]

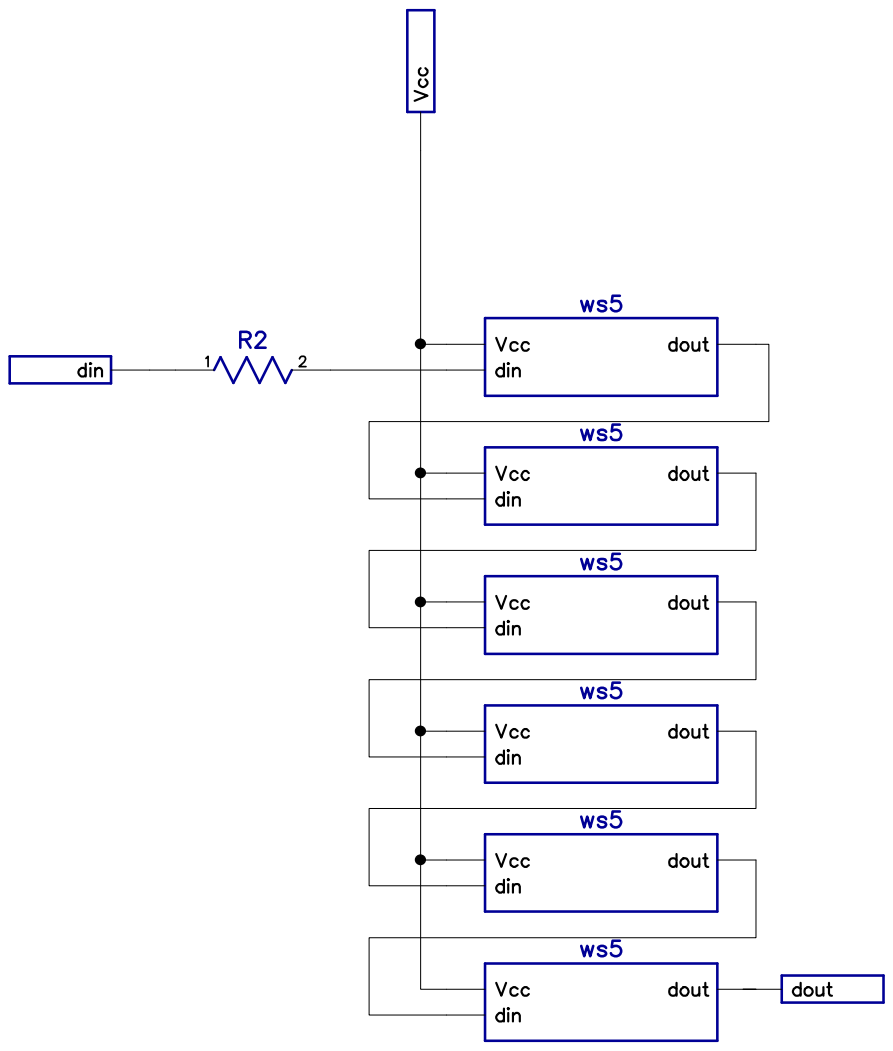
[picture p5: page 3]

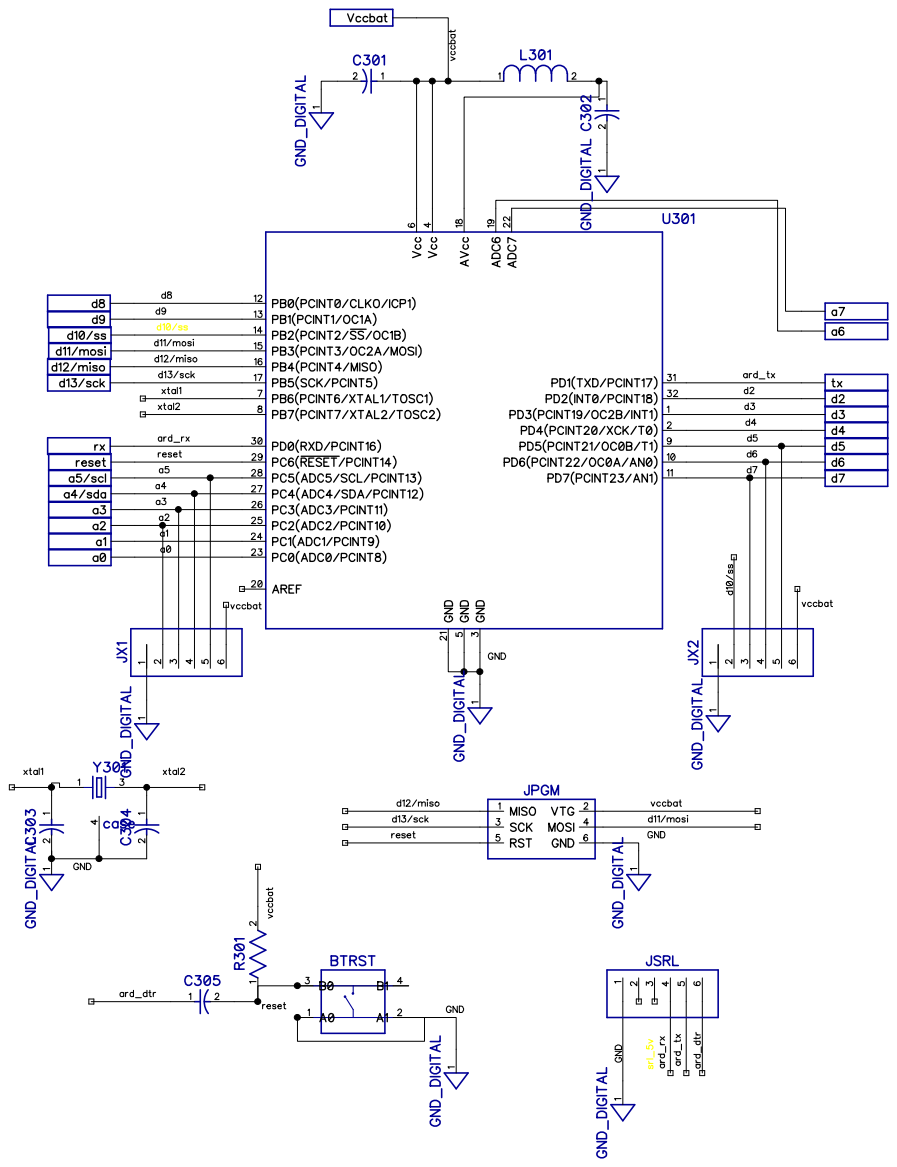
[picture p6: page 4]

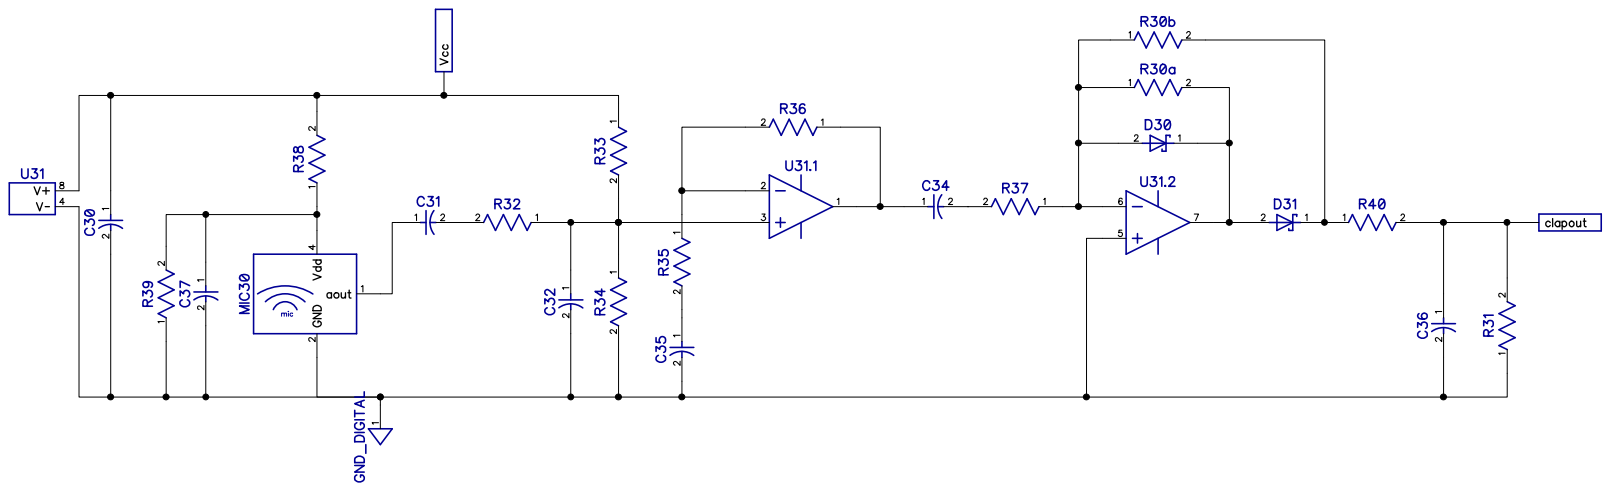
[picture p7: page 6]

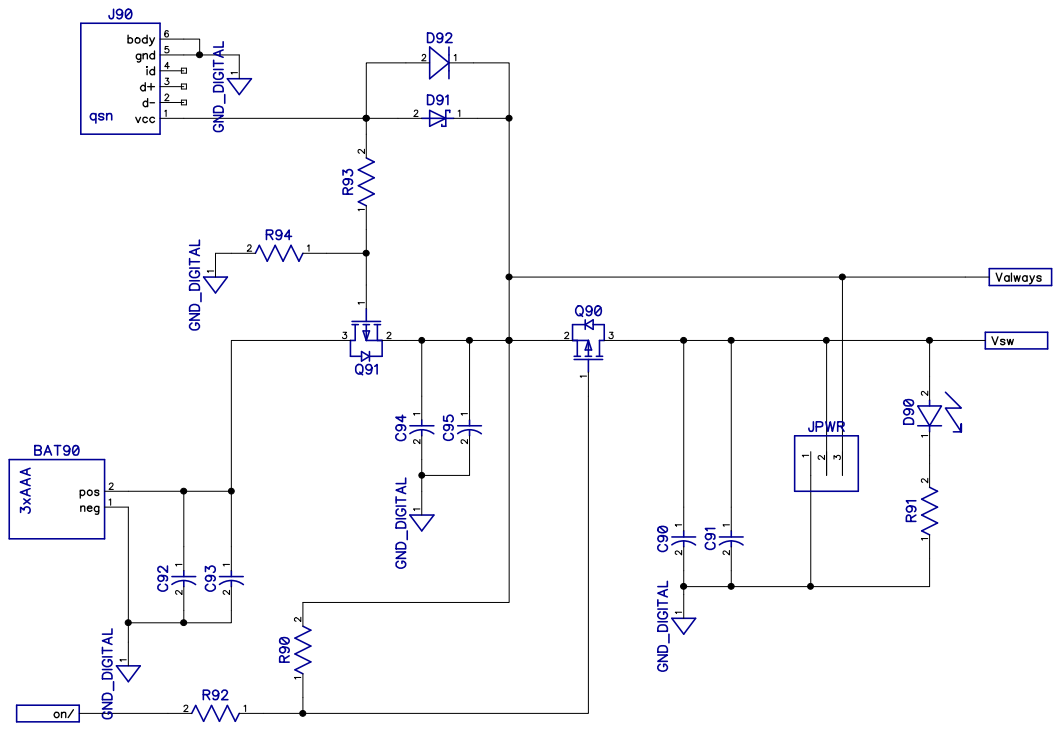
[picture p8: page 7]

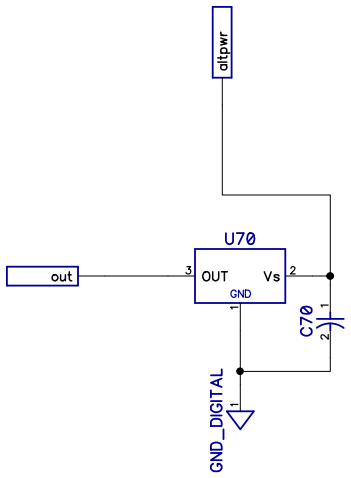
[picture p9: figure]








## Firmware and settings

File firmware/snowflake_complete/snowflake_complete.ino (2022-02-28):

///////////////////////////////////////////////
// 
// Copyright 2019 South Berkeley Electronics
// All Rights Reserved
//
// Arduino sketch to control an LED snowflake.
//
// Author: Dave Jacobowitz (dave@southberkeleyelectronics.com)
//
///////////////////////////////////////////////


#include <Arduino.h>
#include "debug.h"
#include "helpers.h"
#include "bpress.h"
#include "sensors.h"
#include "pixchain.h"
#include "fun_stuff.h"
#include "stored.h"
#include "powerctrl.h"
#include "ir.h"

// defintions of different button press lengths
const uint16_t  SHORT_PRESS_MILLIS      = 200;
const uint16_t  MED_PRESS_MILLIS        = 1000;
const uint16_t  LONG_PRESS_MILLIS       = 8000;
const uint32_t  PATTERN_DURATION_MILLIS = 30000;

// total number of "pixels"
const uint8_t   PIXEL_CHAIN_LENGTH = 30;
const uint32_t  ALL_LIGHTS_MSK     = 0x3fffffff;

// Pin assignments
const uint8_t   PIXEL_OUTPUT_PIN   = 4;
const uint8_t   BUTTON1_PIN        = 9;
const uint8_t   BUTTON2_PIN        = 8;
const uint8_t   LIGHT_PIN          = A1;
const uint8_t   SOUND_PIN          = A0;
const uint8_t   NOISE_PIN          = A7;
const uint8_t   RF_PIN             = A6;
const uint8_t   LED_PWR_CTRL_PIN   = A2;
const uint8_t   IR_PWR_CTRL_PIN    = A3;
const uint8_t   IR_PIN             = 2;
const uint8_t   LOWVOLT_LED_PIN    = 3;

// voltage levels that define when to shut down
// (rather than drain batteries until they leak)
const uint16_t  MIN_VOLTS_MV       = 3000UL;
const uint16_t  EXTERNAL_MV_THRESH = 4800UL;
const uint8_t   MAX_LOWVOLT_ITERS  = 30;

// user-selectable loop delays between led updates
// faster than 70ms between updates and the IR remote cannot function with 
// 32b codes like the NEC codes in the cheap AliExpress remotes. For remotes 
// with 16b codes (sony), 20ms is sufficient.
const uint16_t delays[]          PROGMEM = { 70, 100, 200, 500, 1000, 5000, 5, 20, 40 };

// user selectable max brightnesses
const uint8_t  brightnesses[]    PROGMEM = { 50, 100, 150, 200, 25 };
// user selectable delay before turnoff, in increments of 5 minutes
const uint8_t on_times_5mins[]   PROGMEM = { 6, 12, 24, 36, 72, 144, 255, 1, 3 };

typedef struct varn_indices_t {
    uint8_t pattern_idx;
    uint8_t delay_idx;
    uint8_t brite_idx;
    uint8_t turnoff_idx;
    uint8_t sound_idx;
    uint8_t var0_idx;
    uint8_t auto_idx;
} varn_indices_t;

const uint8_t  VARIATION_0_COUNT = 8;

varn_indices_t varn_indices;


//#pragma GCC diagnostic push
//#pragma GCC diagnostic ignored "-Wc++11-extensions"

template<uint8_t PIN>
using Button_sc = Button_c<PIN, SHORT_PRESS_MILLIS, MED_PRESS_MILLIS, LONG_PRESS_MILLIS>;
Button_sc<BUTTON1_PIN> button1;
Button_sc<BUTTON2_PIN> button2;

//#pragma GCC diagnostic pop

typedef PixChain_c<PIXEL_CHAIN_LENGTH, PIXEL_OUTPUT_PIN> PixChain_sc;
PixChain_sc pixels;

typedef Sensors_c<LIGHT_PIN,SOUND_PIN,NOISE_PIN, RF_PIN> Sensors_sc;
Sensors_sc sensors;

void wake_handler(void);

typedef powerControl_c<LED_PWR_CTRL_PIN, IR_PWR_CTRL_PIN> powerControl_sc;
powerControl_sc pctrl(&wake_handler);

const uint8_t IR_WAIT_LOOPS = 100; // how often can a button repeat
typedef ir_c<IR_PIN,IR_WAIT_LOOPS> ir_sc;
ir_sc irdecoder;


// interrupt to be called when device is woken from sleep
void wake_handler(void) {
    sleep_disable();
    // remove the interrupt from the wake handler and let
    // the IR decoder use it again
    detachInterrupt(0);
    irdecoder.restart();
    DEBUG_PRINTLN_F("wakeable woke by interrupt");
    ADCSRA |= bit(ADEN);
    for (uint8_t pcount=0;pcount<20;pcount++) {
        ir_decoded_t d = irdecoder.code();
        // the unit can be woken only with the "power" (off) button
        if (
             (d.status == ir_decoded) &&
             (
               (d.value == ir_button_off_wakeable) ||
               (d.value == ir_button_off_hard)
             )
           ) {
            pctrl.request_reset();
            break;
        }
        delay(250);
    }
    DEBUG_PRINTLN_F("wake_handler compelete");
    DEBUG_FLUSH();
};


Fun_Sparkle_c <PixChain_sc, Sensors_sc, varn_indices_t>
    fun_sparkle(pixels, sensors, varn_indices);
Fun_Chaser_c  <PixChain_sc, Sensors_sc, varn_indices_t>
    fun_chaser(pixels, sensors, varn_indices);
Fun_Rainbow_c <PixChain_sc, Sensors_sc, varn_indices_t>
    fun_rainbow(pixels, sensors, varn_indices);
Fun_Sparse_c  <PixChain_sc, Sensors_sc, varn_indices_t>
    fun_sparse(pixels, sensors, varn_indices);
Fun_Snake_c   <PixChain_sc, Sensors_sc, varn_indices_t, 7> 
    fun_snake(pixels, sensors, varn_indices);
Fun_Leaves_c  <PixChain_sc, Sensors_sc, varn_indices_t>
    fun_leaves(pixels, sensors, varn_indices);
Fun_Flash_c   <PixChain_sc, Sensors_sc, varn_indices_t>
    fun_flash(pixels, sensors, varn_indices);
Fun_Cylon_c   <PixChain_sc, Sensors_sc, varn_indices_t>
    fun_cylon(pixels, sensors, varn_indices);
Fun_Solid_c   <PixChain_sc, Sensors_sc, varn_indices_t>
    fun_solid(pixels, sensors, varn_indices);
Fun_MiniCircle_c   <PixChain_sc, Sensors_sc, varn_indices_t>
    fun_minicircle(pixels, sensors, varn_indices);
Fun_Inching_c<PixChain_sc, Sensors_sc, varn_indices_t>
    fun_inching(pixels, sensors, varn_indices);
Fun_Pulse_c<PixChain_sc, Sensors_sc, varn_indices_t>
    fun_pulse(pixels, sensors, varn_indices);
Fun_Fade_c<PixChain_sc, Sensors_sc, varn_indices_t>
    fun_fade(pixels, sensors, varn_indices);
Fun_Lines_c<PixChain_sc, Sensors_sc, varn_indices_t>
    fun_lines(pixels, sensors, varn_indices);
Fun_Settings_c<PixChain_sc, Sensors_sc, varn_indices_t>
    fun_settings(pixels, sensors, varn_indices);

typedef Fun_Base_c    <PixChain_sc, Sensors_sc, varn_indices_t>  Fun_base_sc;

Fun_base_sc *patterns[] = { 
    &fun_chaser, 
    &fun_sparkle, 
    &fun_rainbow, 
    &fun_sparse,
    &fun_snake,
    &fun_leaves,
    &fun_flash,
    &fun_cylon,
    &fun_solid,
    &fun_minicircle,
    &fun_inching,
    &fun_pulse,
    &fun_fade,
    &fun_lines,
    &fun_settings,
};

stored2_c<varn_indices_t, 0x1> eeprom(varn_indices);


// routine to scale a limited range input to a different
// limited range
template<uint16_t in_min, uint16_t in_max>
uint8_t scale_range(uint16_t in, uint8_t out_min, uint8_t out_max) {
    const uint32_t in_range = in_max - in_min;
    const uint32_t out_range = out_max - out_min;
    uint32_t in_v     = in;
    if (in_v < in_min) in_v = in_min;
    if (in_v > in_max) in_v = in_max;
    in_v -= in_min;
    uint32_t fract = (in_v << 16) / in_range;
    uint32_t out_v = (fract * out_range) >> 16;
    out_v += out_min;
    return out_v;
};


void shutdown(pc_shutdown_mode_t shmode = pctrl_off) {
    DEBUG_PRINTLN_F("top-level shutdown");
    pixels.disable();
    pctrl.shutdown(shmode);
}

typedef enum sound_mode_t {
    SOUND_OFF,
    SOUND_VU,
    SOUND_FLASH,
} sound_mode_t;

typedef enum autochange_mode_t {
    AUTO_STOP,
    AUTO_PATTERN,
    AUTO_VARIATION,
    AUTO_PATTERN_VARIATION,
} autochange_mode_t;


uint32_t last_tick;
uint32_t last_touch;
uint32_t last_autochange;
uint8_t  lowvolt_count;
pc_shutdown_mode_t wake_status;

void lowvolt_preshutdown() {
   pctrl.poweron(false); // turn off the LED power right away
   pinMode(LOWVOLT_LED_PIN,OUTPUT);
   for (uint8_t i=0;i<30; i+=1) {
       digitalWrite(LOWVOLT_LED_PIN,LOW);
       delay(250);
       digitalWrite(LOWVOLT_LED_PIN,HIGH);
       delay(250);
   }
   pinMode(LOWVOLT_LED_PIN,INPUT);
};

void setup() {
    DEBUG_INIT(19200);

    lowvolt_count = 0;
    wake_status = pctrl_running;

    // turn on LED chain
    DEBUG_PRINTLN_F("before LED poweron");
    pctrl.poweron(true);
    delay(250);
    DEBUG_PRINTLN_F("before IR poweron");
    pctrl.alton(true);
    delay(250);

    uint8_t tries = 10;
    while (tries) {
        uint16_t volts = sensors.myVcc();
        if (volts < MIN_VOLTS_MV) {
            tries -= 1;
            if (!tries) {
                pctrl.poweron(false);
                pctrl.alton(false);
                lowvolt_preshutdown();
                shutdown();
            }
            DEBUG_PRINTLN_F("low battery?");
            DEBUG_PVAR(volts);
            delay(100);
        }  else {
            tries = 0;
        }
    }

    pixels.clear();

    DEBUG_PRINTLN_F("before EEP retreive");
    eeprom.retrieve();
    DEBUG_PRINTLN_F("after EEP retreive");

    // This is in case the eeprom has never been written
    if (varn_indices.pattern_idx  >= getLength(patterns))         varn_indices.pattern_idx   = 0;
    if (varn_indices.delay_idx    >= getLength(delays))           varn_indices.delay_idx  = 0;
    if (varn_indices.brite_idx    >= getLength(brightnesses))     varn_indices.brite_idx  = 0;
    if (varn_indices.turnoff_idx  >= getLength(on_times_5mins))   varn_indices.turnoff_idx = 0;
    if (varn_indices.var0_idx     >= VARIATION_0_COUNT)           varn_indices.var0_idx = 0;
    if (varn_indices.sound_idx    >  SOUND_FLASH)                 varn_indices.sound_idx = 0;
    if (varn_indices.auto_idx     >  AUTO_PATTERN_VARIATION)      varn_indices.auto_idx = 0;
    patterns[varn_indices.pattern_idx]->init();
    sensors.reseed();
    last_touch = last_tick = last_autochange = millis();
    DEBUG_PRINTLN_F("setup complete");
};


void loop() {

   bp_t bp1v = button1.pressed();
   bp_t bp2v = button2.pressed();
   ir_decoded_t ircode = irdecoder.code();
   uint16_t ll = sensors.light();
   uint16_t sl = sensors.sound();

   if (bp1v != bp_none) {
       last_touch = last_tick; 
       DEBUG_PVAR(bp1v);
   }
   if (bp2v != bp_none) {
       last_touch = last_tick; 
       DEBUG_PVAR(bp2v);
   }
   if (ircode.status != ir_nothing) {
       DEBUG_PVAR(ircode.status);
       DEBUG_PVAR(ircode.value);
       if (ircode.status == ir_decoded) {
           last_touch = last_tick; 
       }
   }

   uint8_t l_scaled = scale_range<0,500>(ll,10,fromProgMem8(brightnesses,varn_indices.brite_idx));

   uint32_t msk  = ALL_LIGHTS_MSK;
   switch ((sound_mode_t)varn_indices.sound_idx) {
       case SOUND_VU:
           msk = scale2mask<0,3100,PIXEL_CHAIN_LENGTH,ALL_LIGHTS_MSK>(sl);
           break;
       case SOUND_FLASH:
           msk = thresholder(sl) ? ALL_LIGHTS_MSK : 0;
           break;
       default:
           break;
   }

   auto incr_pattern = [&] () {
       wrapIncr(varn_indices.pattern_idx,getLength(patterns));
       DEBUG_PVAR(varn_indices.pattern_idx);
       patterns[varn_indices.pattern_idx]->init();
   };
   auto decr_pattern = [&] () {
       wrapDecr(varn_indices.pattern_idx,getLength(patterns));
       DEBUG_PVAR(varn_indices.pattern_idx);
       patterns[varn_indices.pattern_idx]->init();
   };
   auto incr_variation = [&] () {
       wrapIncr(varn_indices.var0_idx,VARIATION_0_COUNT);
       DEBUG_PVAR(varn_indices.var0_idx);
   };
   auto save_state = [&] () {
       eeprom.store();
   };
   auto incr_mode = [&] () {
       wrapIncr(varn_indices.sound_idx, SOUND_FLASH + 1);
   };
   auto incr_auto = [&] () {
       wrapIncr(varn_indices.auto_idx, AUTO_PATTERN_VARIATION + 1);
       DEBUG_PVAR(varn_indices.auto_idx);
   };
   auto decr_delay = [&] () {
       wrapDecr(varn_indices.delay_idx,getLength(delays));
   };
   auto incr_delay = [&] () {
       wrapIncr(varn_indices.delay_idx,getLength(delays));
   };
   auto incr_brite = [&] () {
       wrapIncr(varn_indices.brite_idx,getLength(brightnesses));
   };
   auto incr_shutdown_delay = [&] () {
       wrapIncr(varn_indices.turnoff_idx,getLength(on_times_5mins));
   };

   switch (bp1v) {
       case bp_short:    incr_pattern(); break;
       case bp_medium:   incr_variation(); break;
       case bp_long:     wake_status = pctrl_off; break;
       case bp_verylong: save_state(); break;
       default: break;
   }
   switch (bp2v) {
       case bp_short:    incr_mode(); break;
       case bp_medium:   incr_delay(); break;
       case bp_long:     incr_brite(); break;
       case bp_verylong: incr_shutdown_delay(); break;
       default: break;
   }

   if (ircode.status == ir_decoded) {
       switch (ircode.value) {
           case ir_button_next_pattern   : incr_pattern(); break;
           case ir_button_prev_pattern   : decr_pattern(); break;
           case ir_button_next_variation : incr_variation(); break;
           case ir_button_save           : save_state(); break;
           case ir_button_next_mode      : incr_mode(); break;
           case ir_button_next_speed     : incr_delay(); break;
           case ir_button_prev_speed     : decr_delay(); break;
           case ir_button_next_brite     : incr_brite(); break;
           case ir_button_off_wakeable   : wake_status = pctrl_wakeable; break;
           case ir_button_off_hard       : wake_status = pctrl_off; break;
           case ir_button_next_ontime    : incr_shutdown_delay(); break;
           case ir_button_next_auto      : incr_auto(); break;
           default: break;
       }
   }

   


   uint32_t now = millis();
   uint32_t tick_elapsed  = now - last_tick;
   uint32_t touch_elapsed = now - last_touch;
   uint16_t del = fromProgMem16(delays, varn_indices.delay_idx);
   uint32_t pat_elapsed   = now - last_autochange;

   if (varn_indices.auto_idx && (pat_elapsed > PATTERN_DURATION_MILLIS)) {
       if (varn_indices.auto_idx & 0x1) {
           varn_indices.pattern_idx = sensors.rand32() % getLength(patterns);
           patterns[varn_indices.pattern_idx]->init();
       };
       if (varn_indices.auto_idx & 0x2) 
           varn_indices.var0_idx = sensors.rand32() % VARIATION_0_COUNT;
       last_autochange = now;
       DEBUG_PVAR(last_autochange);
   }

   if (tick_elapsed > del) {

       /* logic to deal with a shutdown is in this tick fn
          because there is some strange issue where if I call
          pixels.show() anywhere other than here, the first
          pixel glows green no matter what. This is a timing issue
          of some kind and doesn't happen if there is exactly one
          call to pixels.show. Maybe a lto/inlining thing?
       */

       if (wake_status != pctrl_running) {
           pixels.clear();
       } else {
           patterns[varn_indices.pattern_idx]->tick();
       }

       pixels.copyToOut(msk, l_scaled);
       if (irdecoder.isIdle()) {
           pixels.show();
       }

       if (wake_status != pctrl_running) {
           if ((wake_status == pctrl_wakeable) && (sensors.myVcc() < EXTERNAL_MV_THRESH)) {
               DEBUG_PRINTLN_F("Forcing hard off because (probably) on battery.");
               wake_status = pctrl_off;
           }
           DEBUG_PVAR(wake_status);
           shutdown(wake_status);
       }

       last_tick = now;

   } else {
       uint16_t lv_meas = sensors.myVcc();
       if (lv_meas < MIN_VOLTS_MV) {
           DEBUG_PRINTLN_F("Detected low voltage.");
           DEBUG_PVAR(lv_meas);
           lowvolt_count += 1;
           DEBUG_PVAR(lowvolt_count);
       } else {
           lowvolt_count = 0;
       }
       if (lowvolt_count >= MAX_LOWVOLT_ITERS) {
           lowvolt_preshutdown();
           shutdown();
       }
       // there is a 2ms delay inside the sensor read voltage routine
       // delay(2);
   }

   uint32_t turn_off_millis = 
       (uint32_t)fromProgMem8(on_times_5mins,varn_indices.turnoff_idx) * 5UL * 60UL * 1000UL;
   if (touch_elapsed > turn_off_millis) {
       DEBUG_PRINTLN_F("Setting to wakeable shutdwon.");
       wake_status = pctrl_wakeable;
   }
};

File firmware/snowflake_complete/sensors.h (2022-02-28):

#ifndef __sensors_h
#define __sensors_h

#include "debug.h"
#include "ema.h"

const uint32_t DEFAULT_SEED_V = 12345;

template<uint8_t LIGHT_PIN, uint8_t SOUND_PIN, uint8_t RAND_PIN, uint8_t RF_PIN>
class Sensors_c {
    public:
    Sensors_c() : z1(DEFAULT_SEED_V), z2(DEFAULT_SEED_V), z3(DEFAULT_SEED_V), z4(DEFAULT_SEED_V) {
        pinMode(LIGHT_PIN,INPUT);
        pinMode(SOUND_PIN,INPUT);
        pinMode(RAND_PIN,INPUT);
        pinMode(RF_PIN,INPUT);
        light_filter.init(analogRead(LIGHT_PIN));
        sound_filter.init(analogRead(SOUND_PIN));
#ifdef INCLUDE_RF
        rf_filter.init(analogRead(RF_PIN));
#endif
    }

    uint32_t rand32() {
        uint32_t b;
        b  = ((z1 << 6) ^ z1) >> 13;
        z1 = ((z1 & 4294967294U) << 18) ^ b;
        b  = ((z2 << 2) ^ z2) >> 27; 
        z2 = ((z2 & 4294967288U) << 2) ^ b;
        b  = ((z3 << 13) ^ z3) >> 21;
        z3 = ((z3 & 4294967280U) << 7) ^ b;
        b  = ((z4 << 3) ^ z4) >> 12;
        z4 = ((z4 & 4294967168U) << 13) ^ b;
        return (z1 ^ z2 ^ z3 ^ z4);
    }


    // reseeds the PRNG with a few real random numbers
    bool reseed() {
        z1 = trueRand32();
        z2 = trueRand32();
        z3 = trueRand32();
        z4 = trueRand32();
        DEBUG_PRINT_F("reseed ");
        DEBUG_PRINT_FMT(z1, HEX);
        DEBUG_PRINT_F(" ");
        DEBUG_PRINT_FMT(z2, HEX);
        DEBUG_PRINT_F(" ");
        DEBUG_PRINT_FMT(z3, HEX);
        DEBUG_PRINT_F(" ");
        DEBUG_PRINTLN_FMT(z4, HEX);
        // if all the same, that's bad
        bool ok = (z1 ^ z2 ^ z3 ^ z4) != 0;
        if (!ok) {
            z1 = DEFAULT_SEED_V;
            z2 = DEFAULT_SEED_V;
            z3 = DEFAULT_SEED_V;
            z4 = DEFAULT_SEED_V;

        }
        return ok;
    }

    // generates a "pretty good" True random number by
    // repeatedly resampling an unconnected input pin and 
    // using the noise in the LSBs. 
    // Probably not good enough for crypto purposes. :-)
    uint32_t trueRand32() {
        uint32_t nr = last_rand32;
        for (uint8_t i=0;i<4;i++) {
            nr ^= (uint32_t)_makeRandByte(5,3) << (i*8);
        }
        last_rand32 = nr;
        return nr;
    }


    uint16_t light() {
        return light_filter.update(analogRead(LIGHT_PIN));
    }
    uint16_t sound() {
        return sound_filter.update(analogRead(SOUND_PIN) << 4);
    }
#ifdef INCLUDE_RF
    uint8_t rf() {
        return rf_filter.update(analogRead(RF_PIN));
    }
#endif
    uint16_t myVcc() {
        // Read 1.1V reference against AVcc
        // cribbed from: 
        // https://provideyourown.com/2012/secret-arduino-voltmeter-measure-battery-voltage/

       // set the reference to Vcc and the measurement to the internal 1.1V reference
       #if defined(__AVR_ATmega32U4__) || defined(__AVR_ATmega1280__) || defined(__AVR_ATmega2560__)
       ADMUX = _BV(REFS0) | _BV(MUX4) | _BV(MUX3) | _BV(MUX2) | _BV(MUX1);
       #elif defined (__AVR_ATtiny24__) || defined(__AVR_ATtiny44__) || defined(__AVR_ATtiny84__)
       ADMUX = _BV(MUX5) | _BV(MUX0);
       #elif defined (__AVR_ATtiny25__) || defined(__AVR_ATtiny45__) || defined(__AVR_ATtiny85__)
       ADMUX = _BV(MUX3) | _BV(MUX2);
       #else
       ADMUX = _BV(REFS0) | _BV(MUX3) | _BV(MUX2) | _BV(MUX1);
       #endif  

       delay(2);  // settle time
       ADCSRA |= _BV(ADSC);
       while (bit_is_set(ADCSRA,ADSC));
       uint16_t result = ADCL; // must read ADCL first - it then locks ADCH  
       result |= (ADCH << 8);
       result = 1125300L / result; // 1125300 = 1.1*1023*1000
       return result;
    }


    private:
    uint32_t z1, z2, z3, z4;
    uint32_t last_rand32;

    ema_c<uint16_t, uint32_t, 1, 32> light_filter;
    ema_c<uint16_t, uint32_t, 1, 16> sound_filter;
#ifdef INCLUDE_RF
    ema_c<uint8_t,  uint16_t, 1, 32> rf_filter;
#endif

    bool _makeRandBit(uint8_t iters) {
        bool r = 0;
        for (uint8_t i=0;i<iters;i++) {
            uint16_t x0 = analogRead(RAND_PIN);
            // bitwise xor reduction
            uint8_t  x1 = (x0 & 0xff) ^ ((x0 >> 8) & 0xff);
            uint8_t  x2 = (x1 & 0x0f) ^ ((x1 >> 4) & 0x0f);
            uint8_t  x3 = (x2 & 0x03) ^ ((x2 >> 2) & 0x03);
            uint8_t  x4 = (x3 & 0x01) ^ ((x3 >> 1) & 0x01);
            r ^= x4;
        }
        return r;
    }
    uint8_t _makeRandByte(uint8_t iters1, uint8_t iters0) {
        uint8_t ob = 0;
        for (uint8_t iter=0;iter<iters1;iter++) {
            uint8_t b = 0;
            for (uint8_t i=0;i<8;i++) {
                b <<= 1;
                b |= _makeRandBit(iters0);
            }
            ob ^= b;
        }
        return ob;
    }
};


#endif
